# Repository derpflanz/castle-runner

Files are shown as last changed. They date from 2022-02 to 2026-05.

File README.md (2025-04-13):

# castle-runner

This is my hobby project in making a 6502 based 8-bit computer from scratch. The end goal is to have it run Castle Runner, a game I made many moons ago.

# CR Assembler

Castle Runner is built from scratch, including the assembler (new version, written in C). I created my own assembly language dialect to assemble the machine language code. That ML can then be written to a EEPROM. For which I built my own EEPROM programmer.

## Layout

By default, the RESET vector is set to $8000, which is the start of the ROM in the CR001 computer. The VirtualCR001 uses that as well by default. When programming the EEPROM, this vector is sent as the first two bytes and stored in $FFFC/$FFFD in the ROM.

Note that the assembler can have a DATA section at the start, which will cause to use another RESET vector to be written at the start of the .hex file.

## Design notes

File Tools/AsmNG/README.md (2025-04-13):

# Variables

var = value

example

var = $90
var = $4000
somestring = "hello world"

# ASCII literals

'A'

# Labels

label:

# Comments

; comment

# Hardware interrupts

Add a section, like below:

HW_IRQ:
SEI
CLI
RTS

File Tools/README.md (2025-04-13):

# Tools

This dir contains several tools used in creating the CastleRunner computer. 

## AsmNG

A flex/yacc based assembler for the computer. Written from scratch in C.

## EepromProgrammer

The Python client to program the ROM chips. Works with the programmer that can be found in Firmware

## PixelArt

Some tools to make Pixel Art and the needed hex bytes to put them on screen.

## VirtualCR001

A virtual machine to test ROMs

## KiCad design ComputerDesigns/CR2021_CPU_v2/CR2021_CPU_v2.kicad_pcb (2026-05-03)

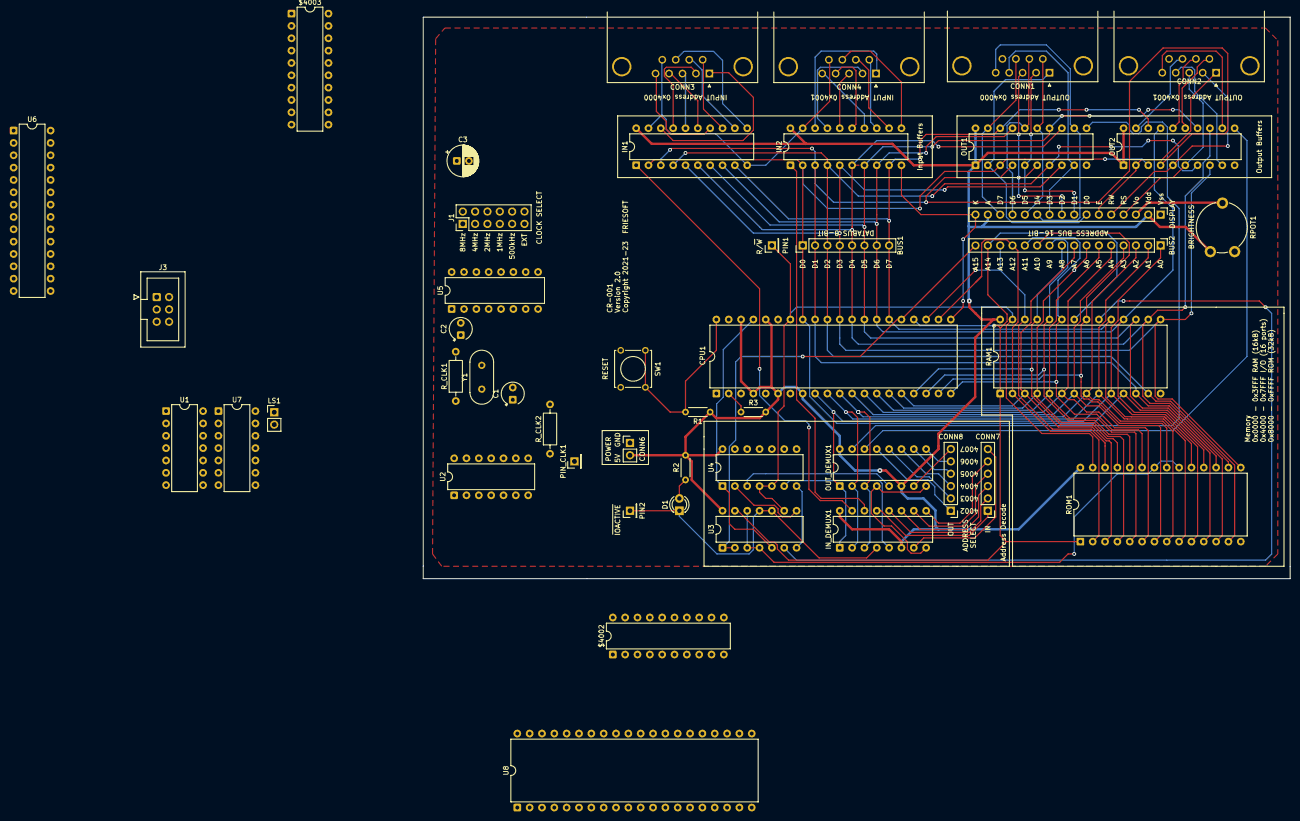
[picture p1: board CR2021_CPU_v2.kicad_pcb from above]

Board: 2 copper layers, 178.4 x 115.6 mm, 47 parts (0 on the bottom side), 99 nets.

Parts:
$4002, $4003: 74LS273; DIP-20_W7.62mm
BUS1: DATABUS_8BIT; PinHeader_1x08_P2.54mm_Vertical
BUS2: ADDRBUS_16BIT; PinHeader_1x16_P2.54mm_Vertical
C1, C2: 22pF; CP_Radial_Tantal_D4.5mm_P2.50mm
C3: 100uF; CP_Radial_D6.3mm_P2.50mm
CONN1: OUT1; DSUB-9_Male_Horizontal_P2.77x2.84mm_EdgePinOffset9.90mm_Hou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
CONN2: OUT2; DSUB-9_Male_Horizontal_P2.77x2.84mm_EdgePinOffset9.90mm_Hou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
CONN3: IN1; DSUB-9_Male_Horizontal_P2.77x2.84mm_EdgePinOffset9.90mm_Hou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
CONN4: IN2; DSUB-9_Male_Horizontal_P2.77x2.84mm_EdgePinOffset9.90mm_Hou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
CONN5: Display; PinHeader_1x16_P2.54mm_Vertical
CONN6: +5V; PinHeader_1x02_P2.54mm_Vertical
CONN7: ADDRSEL_IN; PinHeader_1x06_P2.54mm_Vertical
CONN8: ADDRSEL_OUT; PinHeader_1x06_P2.54mm_Vertical
CPU1: WD65C02S; DIP-40_W15.24mm
D1: IO_Active; LED_D3.0mm
IN1, IN2: 74LS540; DIP-20_W7.62mm
IN_DEMUX1: 74LS138; DIP-16_W7.62mm
J1: Conn_02x06_Odd_Even; PinHeader_2x06_P2.54mm_Vertical
J3: Atmega328 Programmer Interface; IDC-Header_2x03_P2.54mm_Vertical
LS1: Speaker; PinHeader_1x02_P2.54mm_Vertical
OUT1, OUT2: 74LS273; DIP-20_W7.62mm
OUT_DEMUX1: 74LS138; DIP-16_W7.62mm
PIN1: R/!W; PinHeader_1x01_P2.54mm_Vertical
PIN2: !IO_Active; PinHeader_1x01_P2.54mm_Vertical
PIN_CLK1: EXT_CLK; PinHeader_1x01_P2.54mm_Vertical
R1: 1k; R_Axial_DIN0204_L3.6mm_D1.6mm_P5.08mm_Horizontal
R2: 330; R_Axial_DIN0204_L3.6mm_D1.6mm_P5.08mm_Horizontal
R3: 3.3k; R_Axial_DIN0204_L3.6mm_D1.6mm_P5.08mm_Horizontal
RAM1: 32 kB RAM; DIP-28_W15.24mm
ROM1: ROM ZIF Socket; DIP-28_W15.24mm
RPOT1: 10k; Potentiometer_Piher_PT-10-V10_Vertical
R_CLK1: 10M; R_Axial_DIN0207_L6.3mm_D2.5mm_P10.16mm_Horizontal
R_CLK2: 22; R_Axial_DIN0207_L6.3mm_D2.5mm_P10.16mm_Horizontal
SW1: RESET; SW_Tactile_Straight_KSL0Axx1LFTR
U1, U7: LM324; DIP-14_W7.62mm
U2: 74HCU04; DIP-14_W7.62mm
U3, U4: 7400; DIP-14_W7.62mm
U5: 74LS163; DIP-16_W7.62mm
U6: ATmega328-P; DIP-28_W7.62mm
U8: W65C22NxP; DIP-40_W15.24mm
Y1: Crystal 8MHz; Crystal_HC18-U_Vertical

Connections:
$4002_OUT: $4002.11 (Cp), CONN8.1, OUT_DEMUX1.13 (O2), U6.4 (PD2)
$4003_OUT: $4003.11 (Cp), CONN8.2, OUT_DEMUX1.12 (O3), U6.5 (PD3)
+5V: $4002.1 (~Mr), $4002.20 (VCC), $4003.1 (~Mr), $4003.20 (VCC), C3.1, CONN5.2, CONN5.15, CONN6.2, CPU1.4 (~IRQ), CPU1.6 (~NMI), CPU1.8 (VCC), CPU1.36 (BE), CPU1.38 (~SO), IN1.20 (VCC), IN2.20 (VCC), IN_DEMUX1.6 (E3), IN_DEMUX1.16 (VCC), J3.2 (VCC), OUT1.1 (~Mr), OUT1.20 (VCC), OUT2.1 (~Mr), OUT2.20 (VCC), OUT_DEMUX1.6 (E3), OUT_DEMUX1.16 (VCC), R1.1, R2.2, R3.2, RAM1.28 (VCC), ROM1.28 (VCC), RPOT1.3, U1.4 (V+), U2.14 (VCC), U3.14 (VCC), U4.14 (VCC), U5.1 (~MR), U5.7 (CEP), U5.9 (~PE), U5.10 (CET), U5.16 (VCC), U6.7 (VCC), U6.20 (AVCC)
/$4000_IN: IN1.1 (G1), IN_DEMUX1.15 (O0)
/$4000_OUT: OUT1.11 (Cp), OUT_DEMUX1.15 (O0)
/$4001_IN: IN2.1 (G1), IN_DEMUX1.14 (O1)
/$4001_OUT: OUT2.11 (Cp), OUT_DEMUX1.14 (O1)
/A14: BUS2.15, CPU1.24 (A14), RAM1.1 (A14), RAM1.22 (~OE), ROM1.1 (A14), U3.13
/A15: BUS2.16, CPU1.25 (A15), U3.1, U3.2
/Sound/PWM_Sound_Out_Voice2: J3.4 (MOSI), U6.17 (PB3)
CLK: CPU1.37 (PHI2), J1.2, J1.4, J1.6, J1.8, J1.10, J1.12, U3.5, U3.9
DATA0: $4002.3 (D0), $4003.3 (D0), BUS1.1, CPU1.33 (D0), IN1.18 (Y0), IN2.18 (Y0), OUT1.3 (D0), OUT2.3 (D0), RAM1.11 (Q0), ROM1.11 (D0), U6.23 (PC0), U8.33 (D0)
DATA1: $4002.4 (D1), $4003.4 (D1), BUS1.2, CPU1.32 (D1), IN1.17 (Y1), IN2.17 (Y1), OUT1.4 (D1), OUT2.4 (D1), RAM1.12 (Q1), ROM1.12 (D1), U6.24 (PC1), U8.32 (D1)
DATA2: $4002.7 (D2), $4003.7 (D2), BUS1.3, CPU1.31 (D2), IN1.16 (Y2), IN2.16 (Y2), OUT1.7 (D2), OUT2.7 (D2), RAM1.13 (Q2), ROM1.13 (D2), U6.25 (PC2), U8.31 (D2)
DATA3: $4002.8 (D3), $4003.8 (D3), BUS1.4, CPU1.30 (D3), IN1.15 (Y3), IN2.15 (Y3), OUT1.8 (D3), OUT2.8 (D3), RAM1.15 (Q3), ROM1.15 (D3), U6.26 (PC3), U8.30 (D3)
DATA4: $4002.13 (D4), $4003.13 (D4), BUS1.5, CPU1.29 (D4), IN1.14 (Y4), IN2.14 (Y4), OUT1.13 (D4), OUT2.13 (D4), RAM1.16 (Q4), ROM1.16 (D4), U6.27 (PC4), U8.29 (D4)
DATA5: $4002.14 (D5), $4003.14 (D5), BUS1.6, CPU1.28 (D5), IN1.13 (Y5), IN2.13 (Y5), OUT1.14 (D5), OUT2.14 (D5), RAM1.17 (Q5), ROM1.17 (D5), U6.28 (PC5), U8.28 (D5)
DATA6: $4002.17 (D6), $4003.17 (D6), BUS1.7, CPU1.27 (D6), IN1.12 (Y6), IN2.12 (Y6), OUT1.17 (D6), OUT2.17 (D6), RAM1.18 (Q6), ROM1.18 (D6), U6.2 (PD0), U8.27 (D6)
DATA7: $4002.18 (D7), $4003.18 (D7), BUS1.8, CPU1.26 (D7), IN1.11 (Y7), IN2.11 (Y7), OUT1.18 (D7), OUT2.18 (D7), RAM1.19 (Q7), ROM1.19 (D7), U6.3 (PD1), U8.26 (D7)
GND: $4002.10 (GND), $4003.10 (GND), C1.2, C2.2, C3.2, CONN1.9, CONN2.9, CONN3.9, CONN4.9, CONN5.1, CONN5.16, CONN6.1, CPU1.21 (GND), IN1.10 (GND), IN1.19 (G2), IN2.10 (GND), IN2.19 (G2), IN_DEMUX1.8 (GND), J3.6 (GND), LS1.2, OUT1.10 (GND), OUT2.10 (GND), OUT_DEMUX1.8 (GND), RAM1.14 (GND), ROM1.14 (GND), RPOT1.1, SW1.2 (B), U1.11 (V-), U2.7 (GND), U3.7 (GND), U4.7 (GND), U5.3 (D0), U5.4 (D1), U5.5 (D2), U5.6 (D3), U5.8 (GND), U6.8 (GND), U6.22 (GND)
unnamed: BUS2.1, CPU1.9 (A0), IN_DEMUX1.1 (A0), OUT_DEMUX1.1 (A0), RAM1.10 (A0), ROM1.10 (A0)
unnamed: BUS2.2, CPU1.10 (A1), IN_DEMUX1.2 (A1), OUT_DEMUX1.2 (A1), RAM1.9 (A1), ROM1.9 (A1)
unnamed: BUS2.3, CPU1.11 (A2), IN_DEMUX1.3 (A2), OUT_DEMUX1.3 (A2), RAM1.8 (A2), ROM1.8 (A2)
unnamed: BUS2.4, CPU1.12 (A3), RAM1.7 (A3), ROM1.7 (A3)
unnamed: BUS2.5, CPU1.13 (A4), RAM1.6 (A4), ROM1.6 (A4)
unnamed: BUS2.6, CPU1.14 (A5), RAM1.5 (A5), ROM1.5 (A5)
unnamed: BUS2.7, CPU1.15 (A6), RAM1.4 (A6), ROM1.4 (A6)
unnamed: BUS2.8, CPU1.16 (A7), RAM1.3 (A7), ROM1.3 (A7)
unnamed: BUS2.9, CPU1.17 (A8), RAM1.25 (A8), ROM1.25 (A8)
unnamed: BUS2.10, CPU1.18 (A9), RAM1.24 (A9), ROM1.24 (A9)
unnamed: BUS2.11, CPU1.19 (A10), RAM1.21 (A10), ROM1.21 (A10)
unnamed: BUS2.12, CPU1.20 (A11), RAM1.23 (A11), ROM1.23 (A11)
unnamed: BUS2.13, CPU1.22 (A12), RAM1.2 (A12), ROM1.2 (A12)
unnamed: BUS2.14, CPU1.23 (A13), RAM1.26 (A13), ROM1.26 (A13)
unnamed: C1.1, R_CLK1.1, U2.9, Y1.1
unnamed: C2.1, R_CLK1.2, R_CLK2.2, Y1.2
unnamed: CONN1.1, CONN5.7, OUT1.2 (Q0)
unnamed: CONN1.2, CONN5.8, OUT1.5 (Q1)
unnamed: CONN1.3, CONN5.9, OUT1.6 (Q2)
unnamed: CONN1.4, CONN5.10, OUT1.9 (Q3)
unnamed: CONN1.5, CONN5.11, OUT1.12 (Q4)
unnamed: CONN1.6, CONN5.12, OUT1.15 (Q5)
unnamed: CONN1.7, CONN5.13, OUT1.16 (Q6)
unnamed: CONN1.8, CONN5.14, OUT1.19 (Q7)
unnamed: CONN2.1, CONN5.6, OUT2.2 (Q0)
unnamed: CONN2.2, CONN5.5, OUT2.5 (Q1)
unnamed: CONN2.3, CONN5.4, OUT2.6 (Q2)
unnamed: CONN2.4, OUT2.9 (Q3)
unnamed: CONN2.5, OUT2.12 (Q4)
unnamed: CONN2.6, OUT2.15 (Q5)
unnamed: CONN2.7, OUT2.16 (Q6)
unnamed: CONN2.8, OUT2.19 (Q7)
unnamed: CONN3.1, IN1.2 (A0)
unnamed: CONN3.2, IN1.3 (A1)
unnamed: CONN3.3, IN1.4 (A2)
unnamed: CONN3.4, IN1.5 (A3)
unnamed: CONN3.5, IN1.6 (A4)
unnamed: CONN3.6, IN1.7 (A5)
unnamed: CONN3.7, IN1.8 (A6)
unnamed: CONN3.8, IN1.9 (A7)
unnamed: CONN4.1, IN2.2 (A0)
unnamed: CONN4.2, IN2.3 (A1)
unnamed: CONN4.3, IN2.4 (A2)
unnamed: CONN4.4, IN2.5 (A3)
unnamed: CONN4.5, IN2.6 (A4)
unnamed: CONN4.6, IN2.7 (A5)
unnamed: CONN4.7, IN2.8 (A6)
unnamed: CONN4.8, IN2.9 (A7)
unnamed: CONN5.3, RPOT1.2
unnamed: CONN7.1, IN_DEMUX1.13 (O2)
unnamed: CONN7.2, IN_DEMUX1.12 (O3)
unnamed: CONN7.3, IN_DEMUX1.11 (O4)
unnamed: CONN7.4, IN_DEMUX1.10 (O5)
unnamed: CONN7.5, IN_DEMUX1.9 (O6)
unnamed: CONN7.6, IN_DEMUX1.7 (O7)
unnamed: CONN8.3, OUT_DEMUX1.11 (O4)
unnamed: CONN8.4, OUT_DEMUX1.10 (O5)
unnamed: CONN8.5, OUT_DEMUX1.9 (O6)
unnamed: CONN8.6, OUT_DEMUX1.7 (O7)
unnamed: CPU1.2 (RDY), R3.1
unnamed: CPU1.40 (~RESET), R1.2, SW1.1 (A)
unnamed: D1.2 (A), R2.1
unnamed: D1.1 (K), IN_DEMUX1.4 (E1), OUT_DEMUX1.4 (E1), PIN2.1, U3.11
unnamed: IN_DEMUX1.5 (E2), U3.10, U4.6
unnamed: J1.1, R_CLK2.1, U2.8, U5.2 (CP)
unnamed: J1.3, U5.14 (Q0)
unnamed: J1.5, U5.13 (Q1)
unnamed: J1.7, U5.12 (Q2)
unnamed: J1.9, U5.11 (Q3)
unnamed: J1.11, PIN_CLK1.1
unnamed: J3.1 (MISO), U6.18 (PB4)
unnamed: J3.5 (RST), U6.1 (~RESET/PC6)
unnamed: J3.3 (SCK), U6.19 (PB5)
unnamed: LS1.1, U1.7
unnamed: OUT_DEMUX1.5 (E2), U3.8
unnamed: RAM1.20 (~CS), U3.6
unnamed: ROM1.20 (~CS), ROM1.22 (~OE), U3.3, U3.4, U3.12
unnamed: U1.5 (+), U7.1, U7.2 (-)
R/!W: CPU1.34 (R/~W), PIN1.1, RAM1.27 (~WE), ROM1.27 (~WE), U4.4, U4.5

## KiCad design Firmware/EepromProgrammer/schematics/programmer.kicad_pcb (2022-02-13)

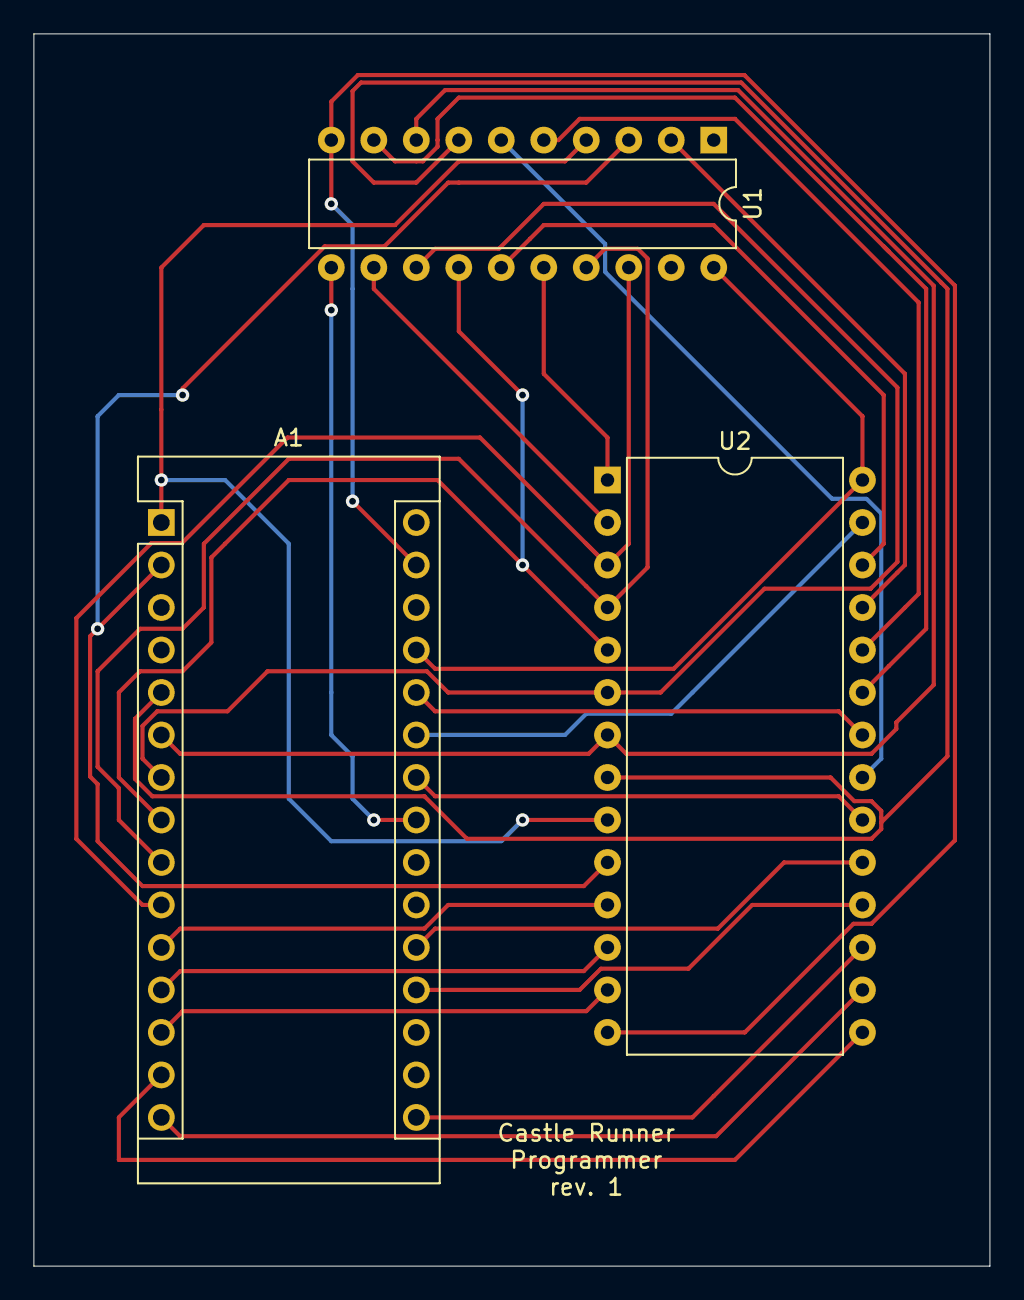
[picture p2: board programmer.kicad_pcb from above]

Board: 2 copper layers, 57.2 x 73.7 mm, 3 parts (0 on the bottom side), 29 nets.

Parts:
A1: Arduino_Nano_v3.x; Arduino_Nano
U1: 74LS273; DIP-20_W7.62mm
U2: KM62256CLP; DIP-28_W15.24mm

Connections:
unnamed: A1.1, U1.4, U2.9
unnamed: A1.2, U1.3, U2.10
unnamed: A1.5, U1.7, U2.8
unnamed: A1.6, U1.8, U2.7
unnamed: A1.7, U1.13, U2.6
unnamed: A1.8, U1.14, U2.5
unnamed: A1.9, U1.17, U2.4
unnamed: A1.10, U1.18, U2.3
unnamed: A1.11, U2.11
unnamed: A1.12, U2.12
unnamed: A1.13, U2.13
unnamed: A1.14, U2.15
unnamed: A1.15, U2.16
unnamed: A1.16, U2.17
unnamed: A1.19, U2.18
unnamed: A1.20, U2.19
unnamed: A1.23, U1.11
unnamed: A1.24, U2.20
unnamed: A1.25, U2.27
unnamed: A1.26, U2.22
unnamed: A1.27, U1.1, U1.20, U2.28
unnamed: A1.29, U1.10, U2.14
unnamed: U1.2, U2.25
unnamed: U1.5, U2.24
unnamed: U1.6, U2.21
unnamed: U1.9, U2.23
unnamed: U1.12, U2.2
unnamed: U1.15, U2.26
unnamed: U1.16, U2.1

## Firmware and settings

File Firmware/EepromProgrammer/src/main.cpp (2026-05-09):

#include "memory.h"
#include "communication.h"
#include <Arduino.h>

struct header {
  uint16_t start_address;       // address where to start reading/writing
  uint16_t length;              // length of read/write
  uint16_t resb;                // value to store in the RESB vector (0xfffc-0xfffd)
  uint16_t irq;                 // value to store in the IRQ/BRK vector (0xfffe-0xffff)
  uint16_t nmi;                 // value to store in the NMI vector (0xfffa-0xfffb)
};

void setup() {
  Communication.setup();
  Memory.setup();
}

uint16_t get_decimal(byte separator) {
  byte digit = 0;
  uint16_t result = 0;

  while ( (digit = Communication.receiveByte()) != separator) {
    result = (result * 10) + (digit - '0');
  }

  return result;
}

uint16_t get_address(byte separator) {
  byte digit = 0;
  uint16_t result = 0;
  while ( (digit = Communication.receiveByte()) != separator) {
    if (digit >= '0' && digit <= '9')
      result = (result * 16) + (digit - '0');

    digit |= 0x20;      // make lower case
    if (digit >= 'a' && digit <= 'f') 
      result = (result * 16) + (digit - 'a') + 10;
  }

  return result;
}

void idle() {
  byte recv;
  do {
    recv = Communication.receiveByte();
  } while (recv != SYN);

  Communication.printf("EEPROM Programmer v2");
  Communication.sendByte(SYN);
}

byte receive_header(header *the_header) {
  byte digit, recv, command = CMD_NOTHING;

  do {
    recv = Communication.receiveByte();
  } while (recv != SOH);

  the_header->length = 0;
  command = Communication.receiveByte();

  the_header->start_address = get_address(US);
  the_header->length = get_decimal(US);
  the_header->resb = get_address(US);
  the_header->irq = get_address(ETB);
 
  if ((the_header->start_address + the_header->length) <= HEXFILE_MAX_SIZE) {
    Communication.sendByte(ACK);
  } else {
    Communication.sendByte(NAK);
    command = CMD_ERROR;
  }

  return command;
}

void receive_data(uint16_t start_address, unsigned long data_length) {
  byte recv;
  do {
    recv = Communication.receiveByte();
  } while (recv != STX);

  unsigned int address = start_address;

  for (int i = 0; i < data_length; i++) {
    recv = Communication.receiveByte();
    Memory.writeByte(address, recv);

    address++;
  }

  // Flush any remaining buffered data
  Memory.flushPageBuffer();

  do {
    recv = Communication.receiveByte();
  } while (recv != ETX);
}

void write_vector(uint16_t vector, uint16_t address) {
  // the vector is a uint, so we need to make this little-endian again
  byte vector_lo = vector & 0x00FF;
  byte vector_hi = vector >> 8;

  Memory.writeByte(address, vector_lo);
  Memory.writeByte(address + 1, vector_hi);
  Memory.flushPageBuffer();
}

void send_data(uint16_t start_addresss, unsigned int data_length) {
  Communication.sendByte(STX);

  for (unsigned int address = start_addresss; address < (start_addresss + data_length); address++) {
    byte data = Memory.readByte(address);
    Communication.sendByte(data);
  }

  Communication.sendByte(ETX);
}

void loop() {
  header the_header;
  idle();
  byte command = receive_header(&the_header);

  if (command == CMD_WRITE_CODE_EEPROM) {
    // not the 0x7ffc/0x7ffe because we write onto a 32kB EEPROM
    // these addresses translate to 0xfffc and 0xfffe on the 6502
    // because the RAM has addresses 0x000-0x7fff
    write_vector(the_header.resb, 0x7ffc);
    write_vector(the_header.irq, 0x7ffe);
    receive_data(the_header.start_address, the_header.length);
  } else if (command == CMD_READ_EEPROM) {
    send_data(the_header.start_address, the_header.length);
  } else if (command == CMD_WRITE_DATA_EEPROM) {
    // when writing plain data, we do not touch the RESB and IRQ vectors
    receive_data(the_header.start_address, the_header.length);
  }
  
  Communication.sendByte(EOT);
}

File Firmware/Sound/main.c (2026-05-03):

#define F_CPU 16000000UL

#include <avr/interrupt.h>
#include <stdlib.h>
#include "sound.h"
#include "io.h"

// external registers
#define REG_CTRL        0
#define REG_FREQ_8BIT   1
#define REG_ATTK_8BIT   2
#define REG_DCAY_8BIT   3
#define REG_SUST_8BIT   4
#define REG_RLSE_8BIT   5

#define REGTYPE_8BIT    0
#define REGTYPE_16BIT   1

// Control bitmasks
#define CTRL_PLAY       1
#define CTRL_SAWT       2
#define CTRL_SINE       4
#define CTRL_TRNG       8

struct note happy_birthday[] = {
    { O4_C, 10, 10,  10, 10 },
    { REST,  1,  1,  10,  1 },
    { O4_C, 10, 10,  10, 10 },
    { REST,  1,  1,  10,  1 },
    { O4_D, 10, 10,  80, 10 },
    { REST,  1,  1,  10,  1 },
    { O4_C, 10, 10,  80, 10 },
    { REST,  1,  1,  10,  1 },
    { O4_F, 10, 10,  80, 10 },
    { REST,  1,  1,  10,  1 },
    { O4_E, 10, 10, 160, 10 },
    { END,   1,  1,   1,  1 }
};

struct note happy_birthday2[] = {
    { REST,  1,  1,  10,  1 },
    { REST,  1,  1,  10,  1 },
    { O4_C, 10, 10,  10, 10 },
    { REST,  1,  1,  10,  1 },
    { O4_D, 10, 10,  80, 10 },
    { REST,  1,  1,  10,  1 },
    { O4_C, 10, 10,  80, 10 },
    { REST,  1,  1,  10,  1 },
    { O4_F, 10, 10,  80, 10 },
    { REST,  1,  1,  10,  1 },
    { O4_E, 10, 10, 160, 10 },
    { END,   1,  1,   1,  1 }
};

struct note current_note[] = 
{
    { O4_C, 10, 10, 10, 10 },
    { END,  1, 1, 1, 1 }
};

// The chip works with a register selector and a data channel
// Interrupt 0 selects the register to use (0-255)
// Interrupt 1 reads the data and writes it into the selected register
uint16_t *current_register;
int reg_type = REGTYPE_8BIT;
uint16_t ctrl_reg;

ISR(INT0_vect) {
    ctrl_reg = 0;
    current_register = NULL;
        
    // Select register (0-255)
    uint8_t reg = data();
    if ((reg & 0xf0) == 0) {
        reg_type = REGTYPE_8BIT;
    }

    switch (reg) {
        case REG_CTRL:
            current_register = &ctrl_reg;
        break;
        case REG_FREQ_8BIT:
            current_register = &(current_note[0].frequency);
            break;
        case REG_ATTK_8BIT:
            current_register = &(current_note[0].attack);
        break;
        case REG_RLSE_8BIT:
            current_register = &(current_note[0].release);
        break;
        case REG_SUST_8BIT:
            current_register = &(current_note[0].sustain);
        break;
        case REG_DCAY_8BIT:
            current_register = &(current_note[0].decay);
        break;
        default:
        break;
    }
}

// Write data into selected register
ISR(INT1_vect) {
    if (current_register == NULL) return;

    uint8_t d = data();
    *current_register = d;

    if (ctrl_reg != 0) {
        waveform_voice1 = NULL;            // sawtooth is default
        if (ctrl_reg & CTRL_TRNG) {
            waveform_voice1 = triangle;
        }
        if (ctrl_reg & CTRL_SINE)  {
            waveform_voice1 = sine;
        }
        if (ctrl_reg & CTRL_PLAY) {
            start_song_voice1();
        }
    }
}

int main() {
    cli();

    // initialise sound system
    init_freq_timer_voice_1();
    init_freq_timer_voice_2();
    init_duration_timer();
    load_song_voice1(happy_birthday);
    load_song_voice2(happy_birthday2);
    set_speed(500);
    waveform_voice1 = sine;
    waveform_voice2 = NULL;
    init_io();

    sei();
    
    start_song_voice1();
    start_song_voice2();

    // everything is interrupt based, so no futher code needed
    while (1);
}

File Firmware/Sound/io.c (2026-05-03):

#include "io.h"
#include <avr/io.h>

// PD2 => INT0 => Address select (low active)
// PC0-PC5,PD0-PD1 = DATA

void init_io() {
    DDRD &= ~(
        // Set R/!W, DR and CR as INPUTs (no pullup resistor)
        (1 << DDD2) | //(1 << DDD3) | (1 << DDD4) | 

        // Set D6 and D7 as INPUTs (no pullup)
        (1 << DDD0) | (1 << DDD1)
    );

    DDRC &= ~(
        // Set D0-5 as INPUTs (no pullup)
        (1 << DDC0) | (1 << DDC1) | (1 << DDC2) | 
        (1 << DDC3) | (1 << DDC4) | (1 << DDC5) 
    );

    // Configure INT0 (PD2) for a falling edge trigger

    // EICRA = External Interrupt Control Register A
    // ISC0n = Interrupt Sense Control 0 Bit n
    // ISC0 = (1,0) => The falling edge of INT0 generates an interrupt request
    EICRA |= (1 << ISC01);          // SET   ISC01
    EICRA &= ~(1 << ISC00);         // CLEAR ISC00

    // ISC1n = Interrupt Sense Control 1 Bit n
    // ISC1 = (1,0) => The falling edge of INT1 generates an interrupt request
    EICRA |= (1 << ISC11);          // SET   ISC11
    EICRA &= ~(1 << ISC10);         // CLEAR ISC10

    // EIMSK = External Interrupt Mask Register
    // INT0 = Enable INT0
    // INT1 = Enable INT1
    EIMSK |= (1 << INT0);           // SET   INT0
    EIMSK |= (1 << INT1);           // SET   INT1
}

uint8_t data() {
    uint8_t d = 0;

    // read PC0-5
    d |=  (PINC & 0b00111111);
    // read PD0-1
    d |= ((PIND & 0b00000011) << 6);

    return d;
}

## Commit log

2021-01-02 switch to 9600 baud to make it work :))
2021-01-17 Fix SYNC at startup
    [eeprom.py]
2021-01-30 Add 8 output LEDs
2021-01-31 Use 0x7FFA as output to LEDs
2021-01-31 Add counter assembly file
2021-01-31 Add assembler
2021-02-14 Add build script for easy Arduino builds
2021-02-14 Add assemble.sh
2021-04-04 Implement preprocessor for assembler
2021-04-17 Remove serial port processing from interrupt handling
2022-02-13 Add arduino control for new board
2022-02-13 robot arduino
2022-02-13 soundchip arduino
2022-02-13 complete assembler
2022-02-15 wire inputs on lcd
2022-04-18 Remove assemble.sh (use makefile instead)
2023-07-22 Make printing nice
2023-07-22 Fix layout of bytes
    [eeprom.py, main.cpp]
2023-10-08 Enable IRQ interrupts
2023-11-11 Fix addressing in ,X
    [fake6502.c]
2023-11-11 Show printable chars
2024-02-04 Set correct Video RAM address
    [ui.c]
2024-02-24 Move assembler to class
2024-03-09 Add new assembler files
2024-04-14 Add tree printing
2024-04-21 de-globalise statement tree
2024-05-25 Remove generic Arduino projects
2024-05-25 fix string length calc
    [main.c]
2024-05-25 update rom for new assembler
2024-06-01 Improve user readable output for assembler
2025-03-15 Add IOTester tool for Arduino
2025-04-13 Move stuff around
    [pixelart-tool.ods, programmer.kicad_pcb, programmer.sch]
2025-04-13 Add everything
    [CR2021_CPU_v2.kicad_pcb, CR2021_CPU_v2.kicad_sch, clock_circuit.kicad_sch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]
2025-09-13 add sound
    [CR2021_CPU_v2.kicad_pcb, CR2021_CPU_v2.kicad_sch, clock_circuit.kicad_sch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]
2025-09-13 assembler bugfix
2025-11-09 add avrdude device finder
2025-11-09 remove cli/sei in interrupt handlers
2025-11-09 updated schematic with opamp mixer
    [sound.kicad_sch]
2026-05-03 update schematics
    [6522.kicad_sch, CR2021_CPU_v2.kicad_pcb, CR2021_CPU_v2.kicad_sch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]
2026-05-09 add some VIA addresses
    [CR2021_CPU_v2.kicad_sch]
2026-07-11 update schematics to new version
    [6522.kicad_sch, CR2021_CPU_v2.kicad_sch, clock_circuit.kicad_sch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]
2026-07-11 stop tracking schematics history
2026-07-11 fix log window clear
    [ui.c]
2026-07-15 Add ignore for \r in assembler

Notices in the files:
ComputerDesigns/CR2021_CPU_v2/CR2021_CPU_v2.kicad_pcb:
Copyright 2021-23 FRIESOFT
